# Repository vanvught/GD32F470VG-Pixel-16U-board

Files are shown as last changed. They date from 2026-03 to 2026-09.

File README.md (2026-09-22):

See latest [https://github.com/vanvught/Kicad-GD32F470VG-Pixel-16](https://github.com/vanvught/Kicad-GD32F470VG-Pixel-16)

# Archived

Features: 

- 16x 4 Universes pixel output
- 1x SPI Flash ROM for storing the configuration and Art-Net Fail-safe record
- 1x I2C (display)
- 1x UART (programming/debug)

Firmware: [https://github.com/vanvught/GD32F470VG-Pixel-16U](https://github.com/vanvught/GD32F470VG-Pixel-16U)

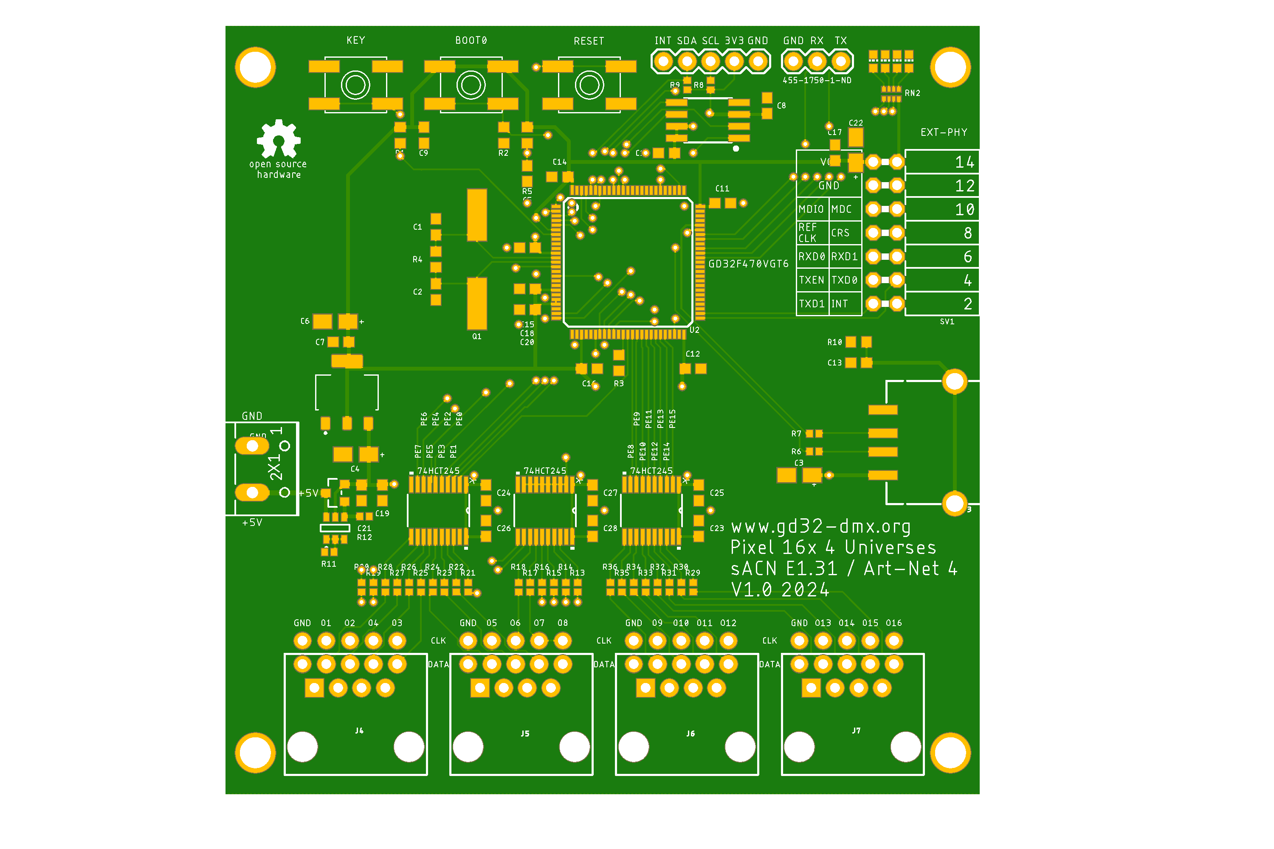
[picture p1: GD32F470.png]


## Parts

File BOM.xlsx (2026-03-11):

Qty | Designator | Footprint | Comment | LCSC Part #
2 | C1, C2 | C0603 | 20pF | C1648
1 | C13 | C0603 | 4700pF/50V | C53987
4 | C3, C4, C6, C22 | A/3216-18R | 10uF | C7171
21 | C5, C7, C8, C9, C10, C11, C12, C14, C15, C16, C17, C18, C19, C20, C21, C23, C24, C25, C26, C27, C28 | C0603 | 100n | C14663
1 | J3 | USB-A-S-SILK-FEMALE | USB_A_SMT_FEMALE | C668591
4 | LED5,LED6,LED7,LED8 | CHIP-LED0603 | PC0 | C72038
1 | Q1 | CSM-7X-DU | 25 MHz | C14872
1 | Q2 | DIODES_INC._DMG2305UX-13_0 | DMG2305UX | C150470
1 | Q3 | DIODES_DMMT5401-7-F_0 | DMMT5401 | C154733
4 | R1, R2, R3, R5 | R0603 | 10K | C25804
2 | R4, R10 | R0603 | 1M | C22935
1 | R11 | R0402 | 10K | C25744
1 | R12 | R0402 | 47K | C25792
24 | R13, R14, R15, R16, R17, R18, R19, R20, R21, R22, R23, R24, R25, R26, R27, R28, R29, R30, R31, R32, R33, R34, R35, R36 | R0402 | 100 | C25076
2 | R6, R7 | R0402 | 22 | C25092
2 | R8, R9 | R0402 | 4K7 | C25900
1 | RN2 | 4X0402ARV341 | 2K | C44891
3 | SW1, SW2, SW3 | EVQ-Q2 | SWITCH | C221880
1 | U1 | SOT229P700X180-4N | AMS1117-3.3 | C6186
1 | U2 | LQFP100 | GD32F470VGT6 | C3029773
1 | U3 | SO08-EIAJ | W25Q128JVSIQ | C97521
3 | U4, U5, U6 | PW20 | 74HCT245 | C10910

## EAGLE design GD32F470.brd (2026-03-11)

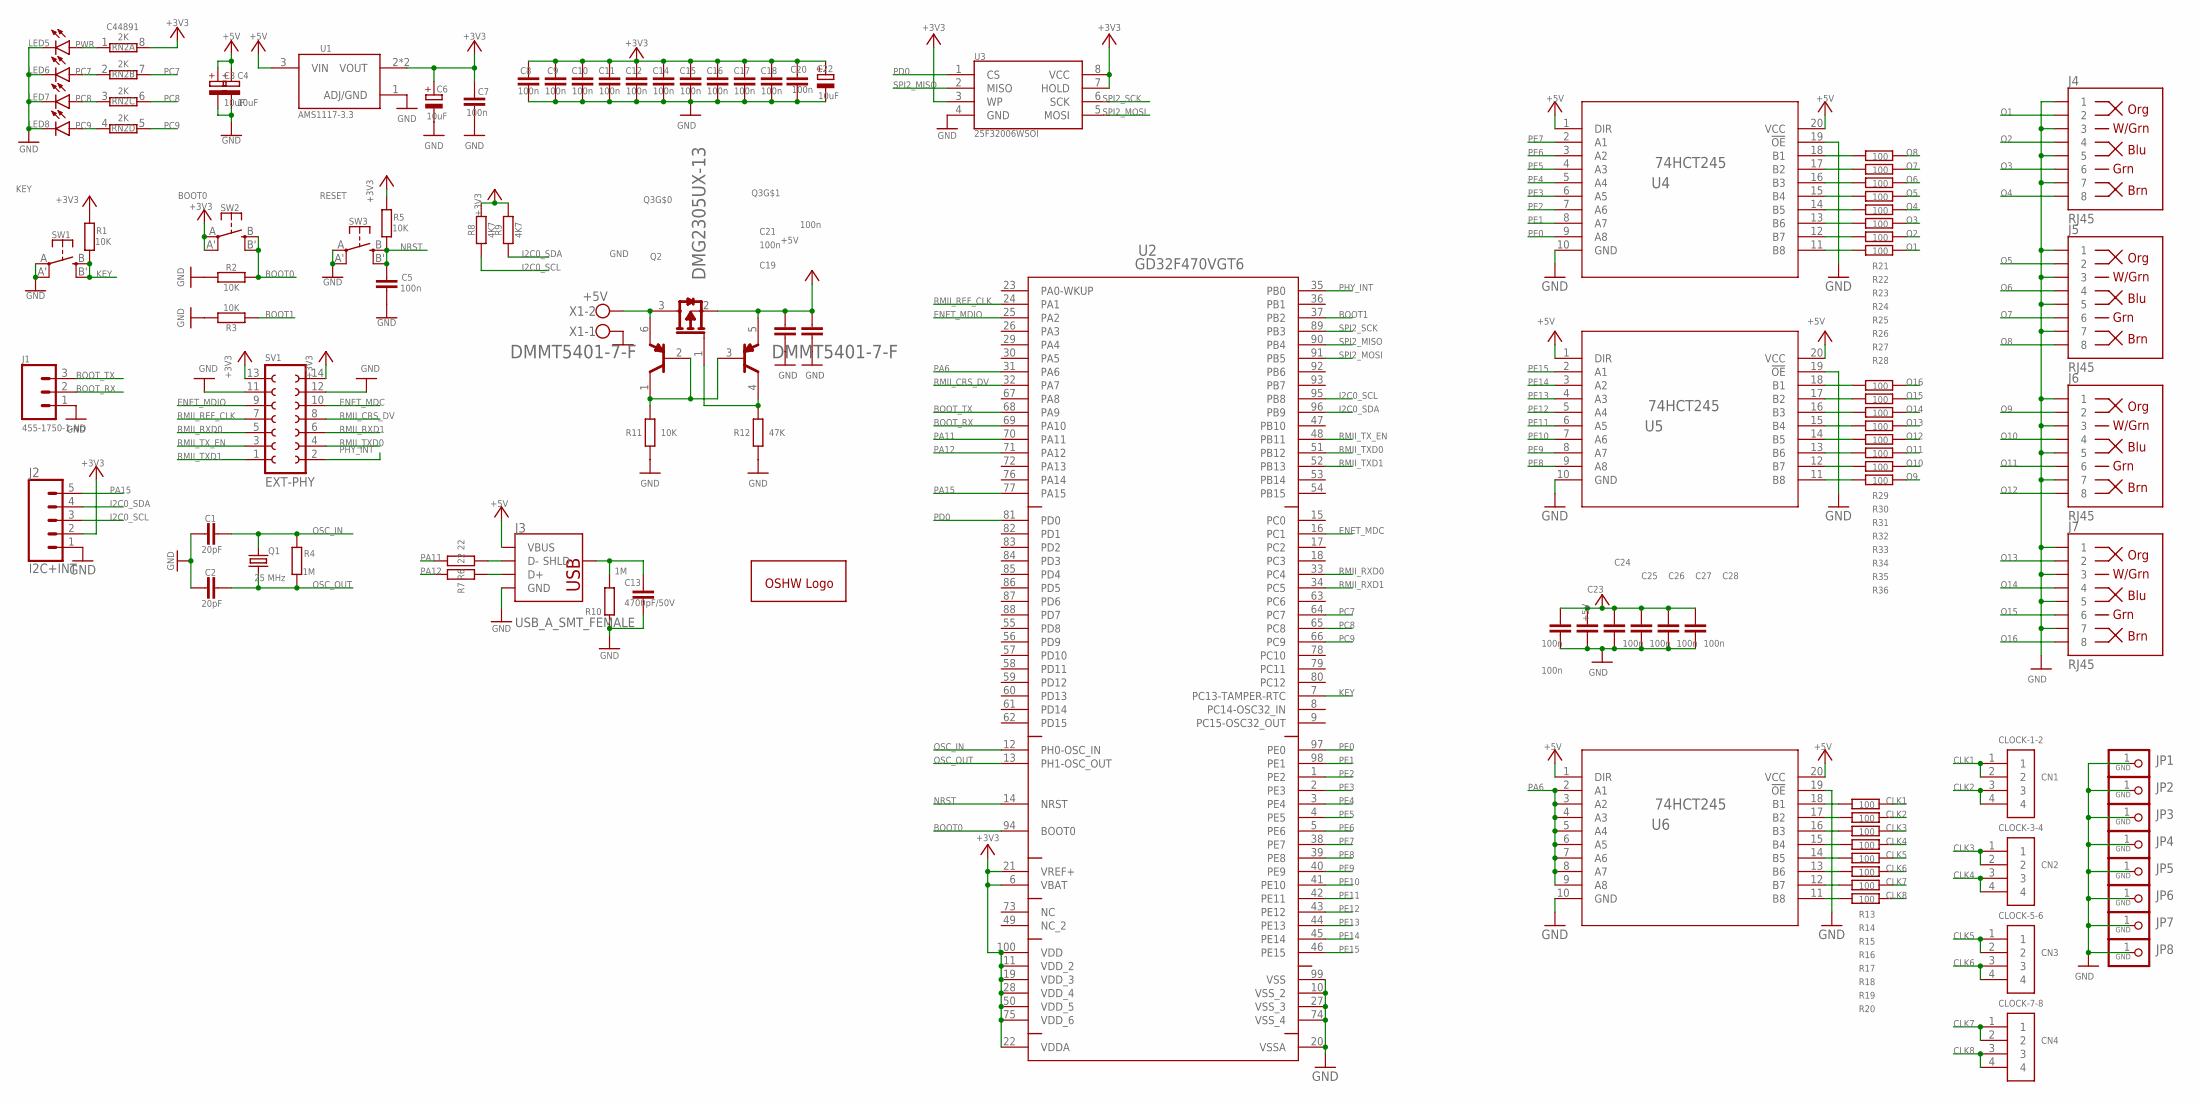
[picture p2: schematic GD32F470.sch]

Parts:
C1, C2: 20pF; C0603; JLCPCB C38523
C3, C4, C6, C22: 10uF; A/3216-18R; JLCPCB C7171
C5, C7, C8, C9, C10, C11, C12, C14, C15, C16, C17, C18, C20, C23, C24, C25, C26, C27, C28: 100n; C0603; JLCPCB C14663
C13: 4700pF/50V; C0603
C19, C21: 100n; C0603
CN1: CLOCK-1-2; 1X04-CLEANBIG
CN2: CLOCK-3-4; 1X04-CLEANBIG
CN3: CLOCK-5-6; 1X04-CLEANBIG
CN4: CLOCK-7-8; 1X04-CLEANBIG
GOLD_ORB_SM1: OSHWLOGOLOGO5MM; OSHW_5MM
J1: 455-1750-1-ND; 1X03
J2: I2C+INT; 1X05
J3: USB_A_SMT_FEMALE; USB-A
J4, J5, J6, J7: RJ45; RJ45-8
JP1, JP2, JP3, JP4, JP5, JP6, JP7, JP8: GND; 1X01-CLEANBIG
LED5: PWR; CHIP-LED0603
LED6: PC7; CHIP-LED0603
LED7: PC8; CHIP-LED0603
LED8: PC9; CHIP-LED0603
Q1: 25 MHz; CSM-7X-DU; JLCPCB C14872
Q2: DMG2305UX; DIODES_INC._DMG2305UX-13_0
Q3: DMMT5401; DIODES_DMMT5401-7-F_0
R1, R2, R3, R5: 10K; R0603; JLCPCB C25804
R4: 1M; R0603; JLCPCB C22935
R6, R7: 22; R0402
R8, R9: 4K7; R0402; JLCPCB C23162
R10: 1M; R0603
R11: 10K; R0402
R12: 47K; R0402
R13, R14, R15, R16, R17, R18, R19, R20, R21, R22, R23, R24, R25, R26, R27, R28, R29, R30, R31, R32, R33, R34, R35, R36: 100; R0402
RN2: 2K; 4X0402ARV341; JLCPCB C44891
SV1: EXT-PHY; FE07-2W
SW1: KEY; EVQ-Q2
SW2: BOOT0; EVQ-Q2; JLCPCB C221880
SW3: RESET; EVQ-Q2
U1: AMS1117-3.3; SOT229P700X180-4N
U2: GD32F470VGT6; LQFP100
U3: 25F32006WSOI; SO08-EIAJ; JLCPCB C97521
U4, U5, U6: 74HCT245; PW20
X1: +5V; W237-102

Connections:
+3V3: C6.+, C7.1, C8.1, C9.1, C10.1, C11.1, C12.1, C14.1, C15.1, C16.1, C17.1, C18.1, C20.1, C22.+, J2.2, R1.2, R5.2, R8.2, R9.2, RN2.8 (2), SV1.13, SV1.14, SW2.A, SW2.A' (P1), U1.2 (VOUT), U1.4 (VOUT), U2.6 (VBAT), U2.11 (VDD_2), U2.19 (VDD_3), U2.21 (VREF+), U2.22 (VDDA), U2.28 (VDD_4), U2.50 (VDD_5), U2.75 (VDD_6), U2.100 (VDD), U3.3 (WP), U3.7 (HOLD), U3.8 (VCC)
+5V: C3.+, C4.+, C19.1, C21.1, C23.1, C24.1, C25.1, C26.1, C27.1, C28.1, J3.VBUS, Q2.2 (S), Q3.5 (E2), U1.3 (VIN), U4.1 (DIR), U4.20 (VCC), U5.1 (DIR), U5.20 (VCC), U6.1 (DIR), U6.20 (VCC)
BOOT0: R2.2, SW2.B (S), SW2.B' (S1), U2.94 (BOOT0)
BOOT1: R3.1, U2.37 (PB2)
BOOT_RX: J1.2, U2.69 (PA10)
BOOT_TX: J1.3, U2.68 (PA9)
CLK1: CN1.1, CN1.2, R13.2
CLK2: CN1.3, CN1.4, R14.2
CLK3: CN2.1, CN2.2, R15.2
CLK4: CN2.3, CN2.4, R16.2
CLK5: CN3.1, CN3.2, R17.2
CLK6: CN3.3, CN3.4, R18.2
CLK7: CN4.1, CN4.2, R19.2
CLK8: CN4.3, CN4.4, R20.2
ENET_MDC: SV1.10, U2.16 (PC1)
ENET_MDIO: SV1.9, U2.25 (PA2)
GND: C1.1, C2.1, C3.-, C4.-, C5.2, C6.-, C7.2, C8.2, C9.2, C10.2, C11.2, C12.2, C13.2, C14.2, C15.2, C16.2, C17.2, C18.2, C19.2, C20.2, C21.2, C22.-, C23.2, C24.2, C25.2, C26.2, C27.2, C28.2, J1.1, J2.1, J3.GND, J4.1, J4.3, J4.5, J4.7, J5.1, J5.3, J5.5, J5.7, J6.1, J6.3, J6.5, J6.7, J7.1, J7.3, J7.5, J7.7, JP1.1, JP2.1, JP3.1, JP4.1, JP5.1, JP6.1, JP7.1, JP8.1, LED5.C, LED6.C, LED7.C, LED8.C, R2.1, R3.2, R10.1, R11.1, R12.1, SV1.11, SV1.12, SW1.A, SW1.A' (P1), SW3.A, SW3.A' (P1), U1.1 (ADJ/GND), U2.10 (VSS_2), U2.20 (VSSA), U2.27 (VSS_3), U2.74 (VSS_4), U2.99 (VSS), U3.4 (GND), U4.10 (GND), U4.19 (!OE), U5.10 (GND), U5.19 (!OE), U6.10 (GND), U6.19 (!OE), X1.1
I2C0_SCL: J2.3, R8.1, U2.95 (PB8)
I2C0_SDA: J2.4, R9.1, U2.96 (PB9)
KEY: R1.1, SW1.B (S), SW1.B' (S1), U2.7 (PC13-TAMPER-RTC)
unnamed: R21.1, U4.18 (B1)
unnamed: Q3.1 (C1), Q3.2 (B1), Q3.3 (B2), R11.2
unnamed: R22.1, U4.17 (B2)
unnamed: R23.1, U4.16 (B3)
unnamed: R24.1, U4.15 (B4)
unnamed: R25.1, U4.14 (B5)
unnamed: R26.1, U4.13 (B6)
unnamed: R27.1, U4.12 (B7)
unnamed: R28.1, U4.11 (B8)
unnamed: R29.1, U5.18 (B1)
unnamed: R30.1, U5.17 (B2)
unnamed: R31.1, U5.16 (B3)
unnamed: R32.1, U5.15 (B4)
unnamed: R33.1, U5.14 (B5)
unnamed: R34.1, U5.13 (B6)
unnamed: R35.1, U5.12 (B7)
unnamed: R36.1, U5.11 (B8)
unnamed: J3.D-, R6.1
unnamed: LED5.A, RN2.1
unnamed: LED6.A, RN2.2 (1)
unnamed: LED7.A, RN2.3 (1)
unnamed: LED8.A, RN2.4 (1)
unnamed: Q2.1 (G), Q3.4 (C2), R12.2
unnamed: Q2.3 (D), Q3.6 (E1), X1.2
unnamed: R13.1, U6.18 (B1)
unnamed: R14.1, U6.17 (B2)
unnamed: R15.1, U6.16 (B3)
unnamed: R16.1, U6.15 (B4)
unnamed: R17.1, U6.14 (B5)
unnamed: R18.1, U6.13 (B6)
unnamed: R19.1, U6.12 (B7)
unnamed: R20.1, U6.11 (B8)
unnamed: J3.D+, R7.1
NRST: C5.1, R5.1, SW3.B (S), SW3.B' (S1), U2.14 (NRST)
O1: J4.2, R28.2
O2: J4.4, R27.2
O3: J4.6, R26.2
O4: J4.8, R25.2
O5: J5.2, R24.2
O6: J5.4, R23.2
O7: J5.6, R22.2
O8: J5.8, R21.2
O9: J6.2, R36.2
O10: J6.4, R35.2
O11: J6.6, R34.2
O12: J6.8, R33.2
O13: J7.2, R32.2
O14: J7.4, R31.2
O15: J7.6, R30.2
O16: J7.8, R29.2
OSC_IN: C1.2, Q1.2, R4.1, U2.12 (PH0-OSC_IN)
OSC_OUT: C2.2, Q1.1, R4.2, U2.13 (PH1-OSC_OUT)
PA6: U2.31 (PA6), U6.2 (A1), U6.3 (A2), U6.4 (A3), U6.5 (A4), U6.6 (A5), U6.7 (A6), U6.8 (A7), U6.9 (A8)
PA11: R6.2, U2.70 (PA11)
PA12: R7.2, U2.71 (PA12)
PA15: J2.5, U2.77 (PA15)
PC7: RN2.7 (2), U2.64 (PC7)
PC8: RN2.6 (2), U2.65 (PC8)
PC9: RN2.5 (2), U2.66 (PC9)
PD0: U2.81 (PD0), U3.1 (CS)
PE0: U2.97 (PE0), U4.9 (A8)
PE1: U2.98 (PE1), U4.8 (A7)
PE2: U2.1 (PE2), U4.7 (A6)
PE3: U2.2 (PE3), U4.6 (A5)
PE4: U2.3 (PE4), U4.5 (A4)
PE5: U2.4 (PE5), U4.4 (A3)
PE6: U2.5 (PE6), U4.3 (A2)
PE7: U2.38 (PE7), U4.2 (A1)
PE8: U2.39 (PE8), U5.9 (A8)
PE9: U2.40 (PE9), U5.8 (A7)
PE10: U2.41 (PE10), U5.7 (A6)
PE11: U2.42 (PE11), U5.6 (A5)
PE12: U2.43 (PE12), U5.5 (A4)
PE13: U2.44 (PE13), U5.4 (A3)
PE14: U2.45 (PE14), U5.3 (A2)
PE15: U2.46 (PE15), U5.2 (A1)
PHY_INT: SV1.2, U2.35 (PB0)
RMII_CRS_DV: SV1.8, U2.32 (PA7)
RMII_REF_CLK: SV1.7, U2.24 (PA1)
RMII_RXD0: SV1.5, U2.33 (PC4)
RMII_RXD1: SV1.6, U2.34 (PC5)
RMII_TXD0: SV1.4, U2.51 (PB12)
RMII_TXD1: SV1.1, U2.52 (PB13)
RMII_TX_EN: SV1.3, U2.48 (PB11)
SHLD: C13.1, J3.SHLD1 (SHLD), J3.SHLD2 (SHLD), R10.2
SPI2_MISO: U2.90 (PB4), U3.2 (MISO)
SPI2_MOSI: U2.91 (PB5), U3.5 (MOSI)
SPI2_SCK: U2.89 (PB3), U3.6 (SCK)

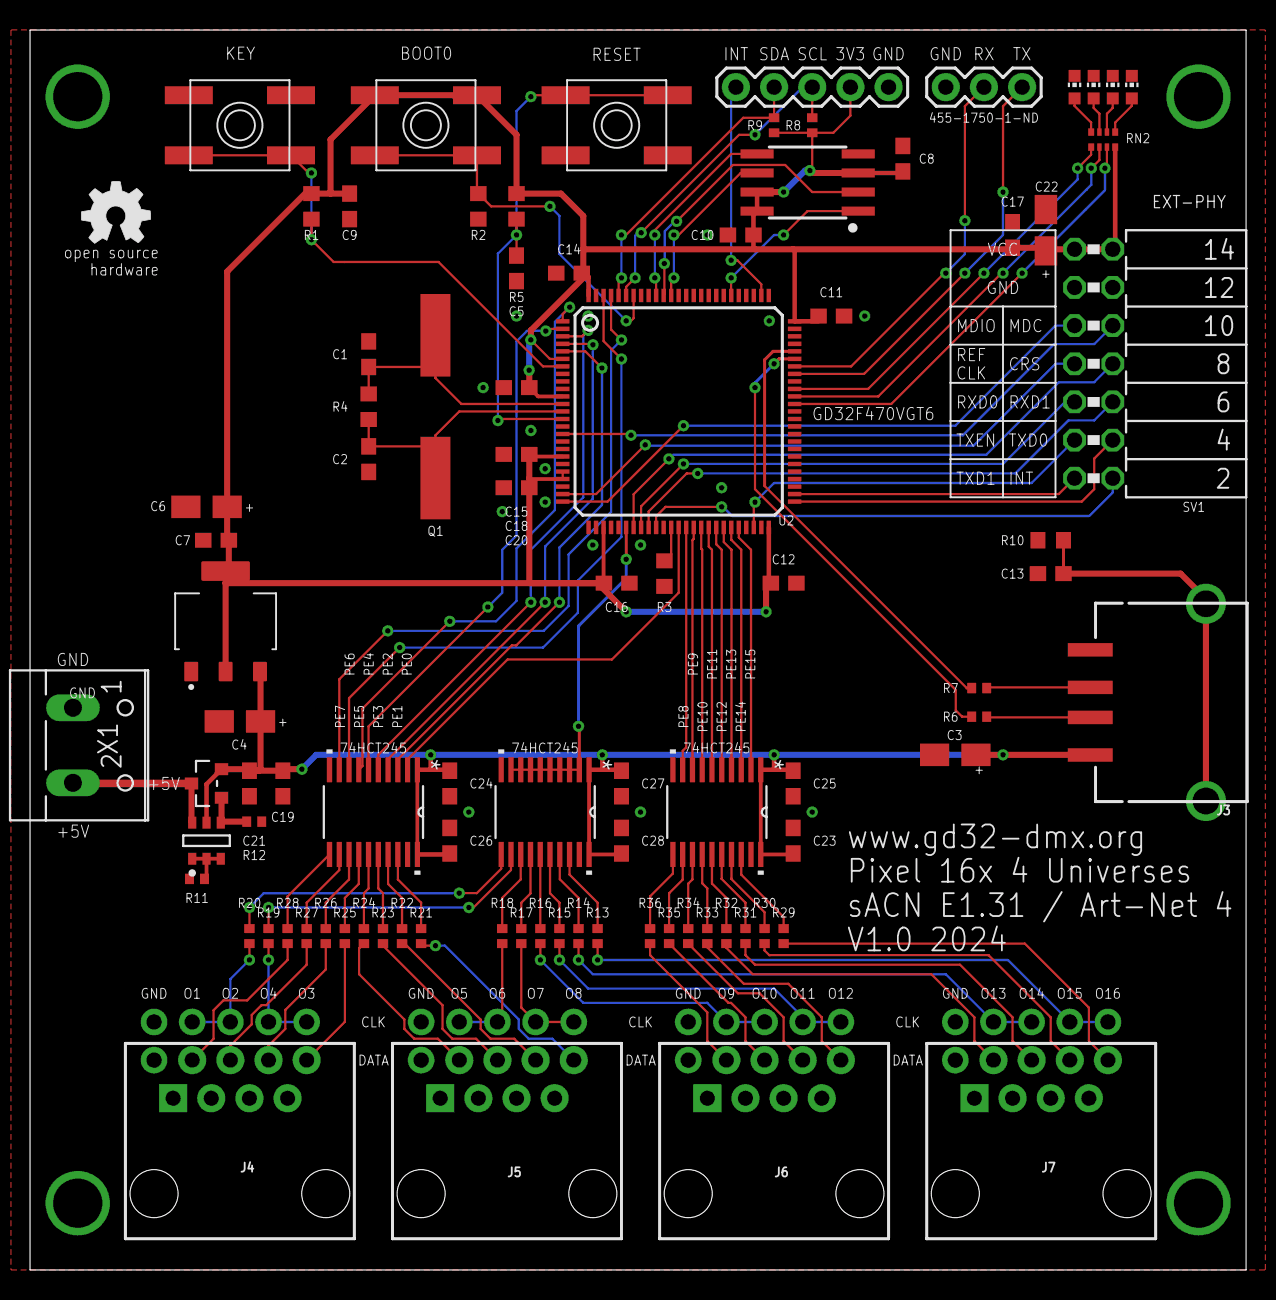
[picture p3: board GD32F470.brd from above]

Board: 2 copper layers, 81.0 x 82.5 mm, 103 parts (0 on the bottom side), 108 nets.

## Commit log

2026-03-11 Replace USB-A footprint
    Swap SparkFun USB-A footprint for a local GD32F USB-A (new library/packages and 3D package), update footprint URNs/library_version for multiple parts (1X03, SO08-EIAJ, 1X05, etc.), and adjust board element attributes (J1, U3, U1) and coordinates. Reroute and reconnect USB nets (VBUS, D+, D-, SHLD) to match the new footprint, add a SHLD signal, and tidy related wire widths/paths. Add new schematic GD32F470.sch and update binary BOM/CPL and Gerber outputs.
    [BOM.xlsx, GD32F470.brd, GD32F470.sch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]
2026-03-20 Add GD32F470 board image and update README
    Add new GD32F470.png board image and expand README with device features, firmware repo link, and embedded image. Improves documentation for the GD32F470 Pixel project and provides quick reference to 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
2026-09-22 Archive project and link to latest repo
    This commit marks the repository as archived and points readers to the maintained replacement project at vanvught/Kicad-GD32F470VG-Pixel-16. The README now redirects users to the latest board design and avoids confusion about the current active project.
    @HFreni
    @batecam79

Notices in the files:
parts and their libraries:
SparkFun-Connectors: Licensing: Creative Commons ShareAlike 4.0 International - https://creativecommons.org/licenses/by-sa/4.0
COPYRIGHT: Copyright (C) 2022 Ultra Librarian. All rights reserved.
